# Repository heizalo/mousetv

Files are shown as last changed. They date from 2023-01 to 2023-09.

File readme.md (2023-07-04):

# MouseTV project:
testIR

This is a work in progress will include a changelog as the project keeps on growing. 

In the most recent version of our Python script, we've changed it to continuously record video to address issues we encountered with door opening and closing. Additionally, we have implemented functionality to save recordings in separate folders with timestamps, making organization and access much more convenient.

2022- tqdm added for progressbar

-This project uses an inexpensive Raspberry Pi 4. Using a python script for triggers and the recording in an operant chamber. This could be paired with DLC or SLEAP as a post process

-Magnetic door sensor added

-Script that uses the mag door sensor was implemented

Early 2023:

-New scripts were generated for run and record

-schedule library has been added for scheduled recordings

-Python script has been changed to continuosly recording due to issues when opening the door and closing.

-New design has been completed

-Excel CSV files will be use to cut/snip videos as a post processing

-tqdm has been removed

May 2023 :

-Library "schedule" was added

-New script generated using schedule added

-Magnetic door sensor was removed

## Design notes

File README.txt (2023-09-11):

This project uses an inexpensive raspberry pi 4. 

Here are some part that will be needed in order to make it work:

-Magnetic door sensor
-Raspberry pi camera CSI connector
-3d printed parts

This code built was created keeping in mind that the Universities Internet security constricted us from uploading files from/to network. In order to adapt to the current restriction this script was developed. The main idea here, is to use opening the door as a trigger to either continue to record or skip to the next name on the video.txt file.

First, power savings mode and the headless feature on a raspberry pi MUST be deactivate/activated 
Second, make sure the right GPIO is selected (no PIN)
Third, this script eventually will have a way to write files into a portable USB flash drive for easy storage and removal.
Fourth, make sure video.txt file has been updated with mouse name and time. Example file as how it can be done is shared , "example-video-txt". The name of the mouse/cohort must be included first adding ".h264" and leaving a space " " and after that adding the time in seconds "100 " 

Currently, the main OS has been cloned and stored for easy access in case the current OS gets corrupted. 

--------------------------------------------------------------------------------------------------------------------------------------------------------------------------------------------------------------------------------

MouseTV project:

This project was created to be able to record and keep track of mice running set schedules, males and females. 

Let's start with the set up and things that you might need in order to have the Raspberry Pi set up:
Version of  Raspberry Pi, we are using the(Legacy) OS normally known as Debian 10 (buster) (https://www.raspberrypi.com/software/operating-systems/)
The easiest way to get it burned/flashed is using Raspberry Pi Imager ( https://www.raspberrypi.com/software/ ) Follow instructions 
Upon hours of testing, it was noticed the power saving mode was putting the Pi to sleep. Power saving mode must be deactivated 

  on terminal:
  go to $sudo nano /etc/xdg/lxsession/LXDE-pi/autostart
  add lines
  @xset s noblank
  @xset s off
  @xset dpms
  
  Go to $sudo nano /etc/lightdm/lightdm.conf
  Add below line in to SeatDefault (or Seat:* in newer LightDM versions) section.
  SeatDefaults]
  xserver-command=X -s 0 -dpms
  Restart your Raspberry Pi.
  
  Lastly, network disabling (power saving mode as well)
  Check ,
  sudo iw wlan0 get power_save
  if it is "on" then execute
  sudo iw wlan0 set power_save off

Normally, there is not a need for a monitor to be connected at all times to the raspberry pi and for that it is necesary to have a "headless" pi, without it, it will not boot if not connected to a monitor. 
Adding hdmi_force_hotplug=1 to /boot/config.txt seems to have solves the problem.

Our interface for running the script is using SSH although due to having new people come into our lab we have opted for using VNC viewer which has a nice UI and facilitates easier connections to each raspberry pi

There are few libraries that will need to be updated as time goes by, this part will be updated with time.

-----------------

Some other updates:
- We are currently looking to the addition for ABET to send signal to make our code more robust. (on the works)
- Building a GUI for easy access for undergrads

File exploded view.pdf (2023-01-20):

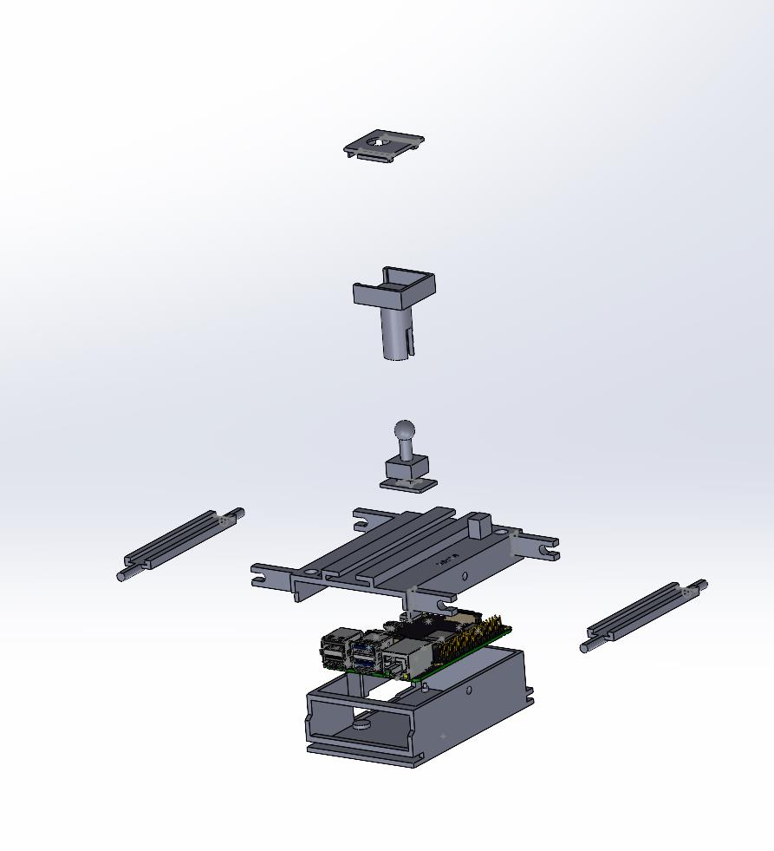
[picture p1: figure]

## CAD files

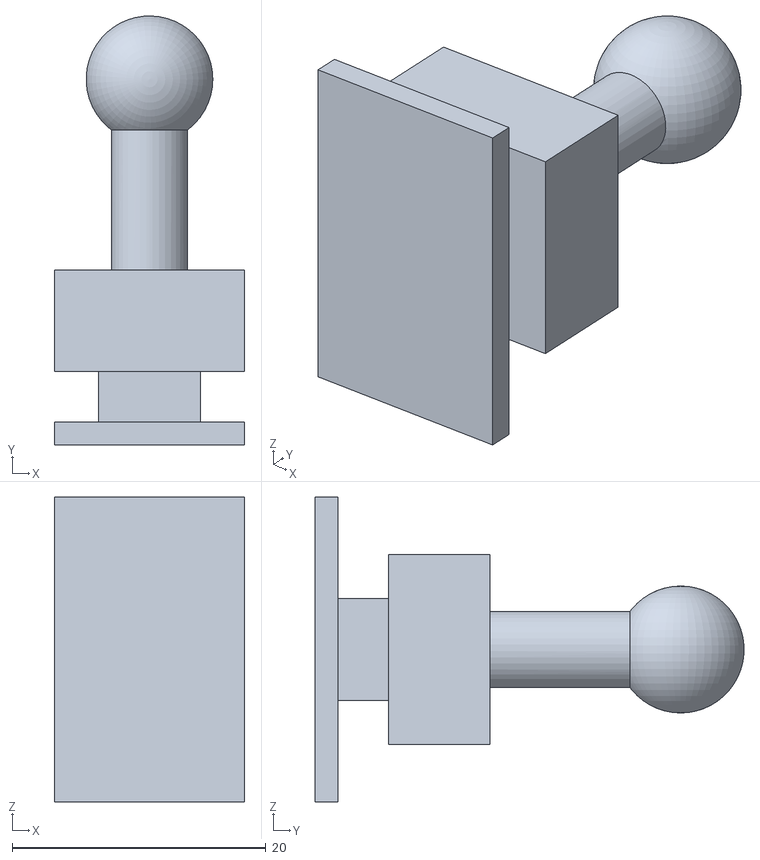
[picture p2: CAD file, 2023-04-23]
stl 2.0/Camera_slider.STL
15.0 x 33.8 x 24.0

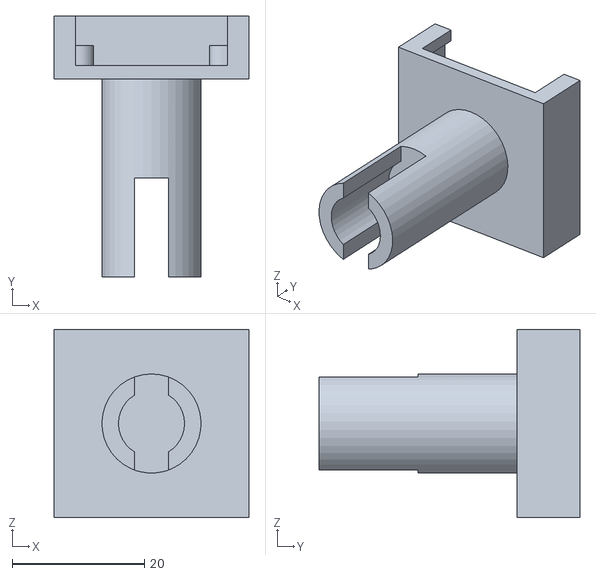
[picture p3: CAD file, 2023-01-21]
stl/CAMERA HOLDER .STL
29.5 x 39.5 x 28.5

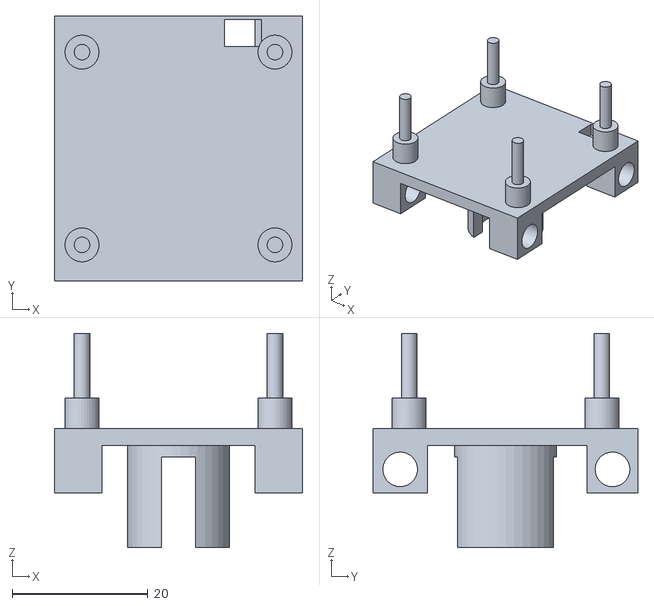
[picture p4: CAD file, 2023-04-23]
stl 2.0/final_bottom_camera.STL
36.5 x 39.0 x 31.5

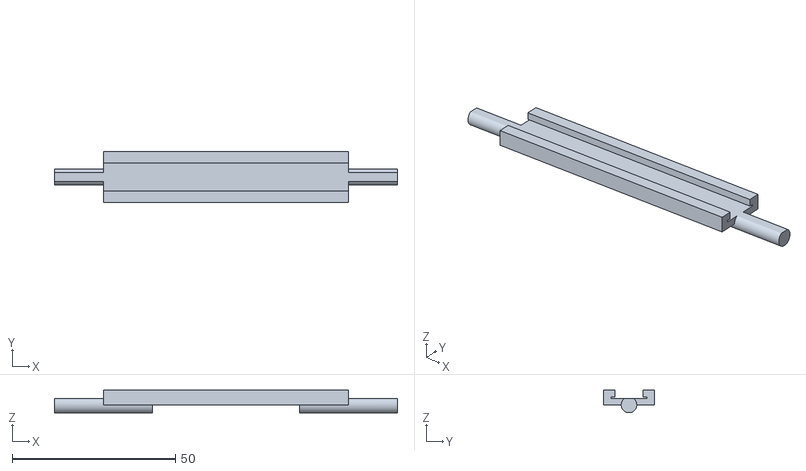
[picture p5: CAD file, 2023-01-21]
stl/LED HOLDER.STL
105.0 x 15.5 x 6.90

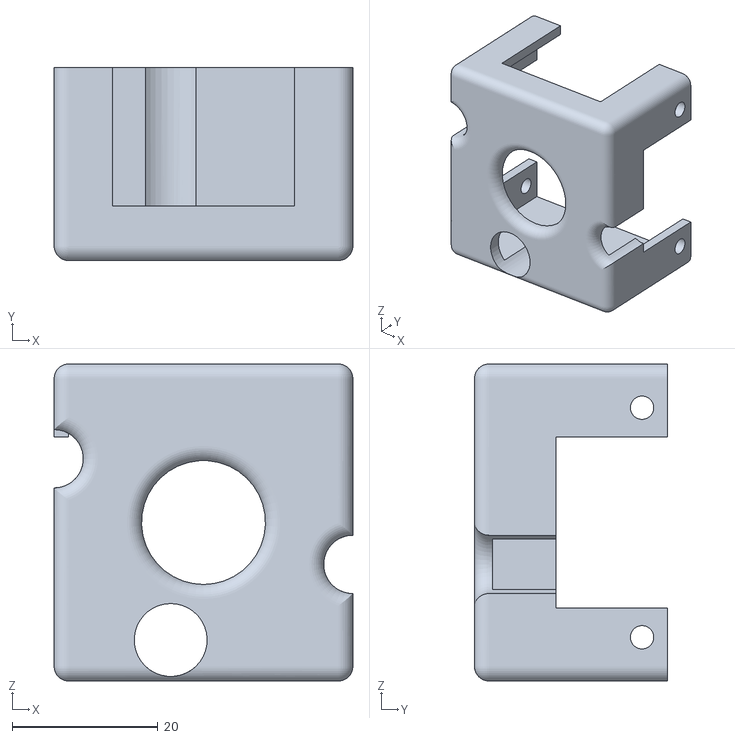
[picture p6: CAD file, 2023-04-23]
stl 2.0/final_top cover.STL
41.0 x 26.5 x 43.5

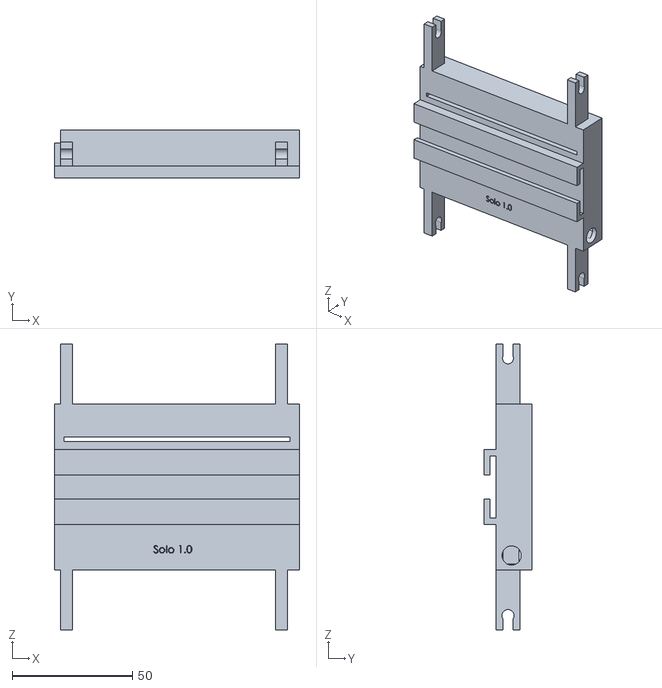
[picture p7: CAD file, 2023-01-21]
stl/TOP LID .STL
102.0 x 20.0 x 119.0

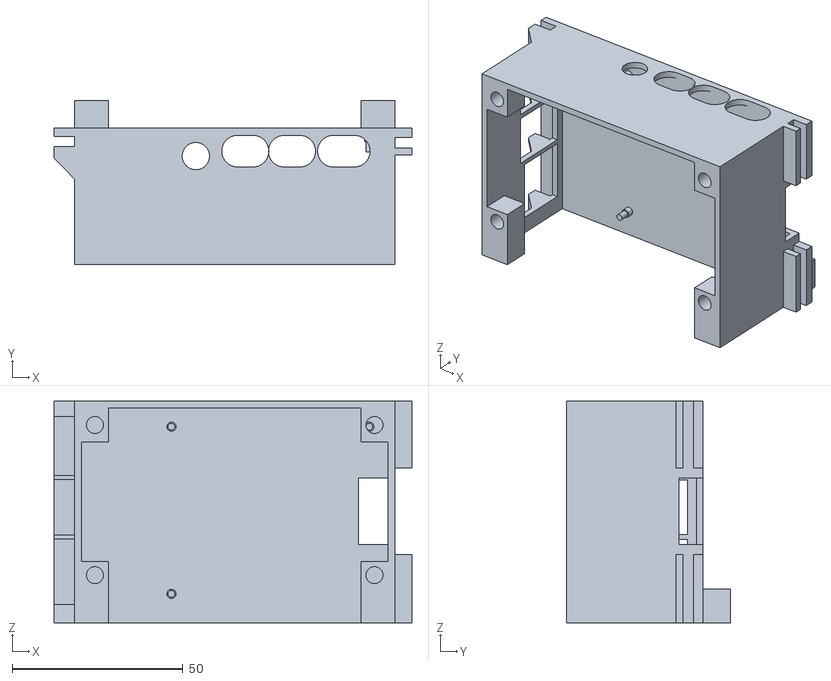
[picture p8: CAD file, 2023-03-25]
stl 2.0/new casing for fan1.STL
104.9 x 48.0 x 65.0

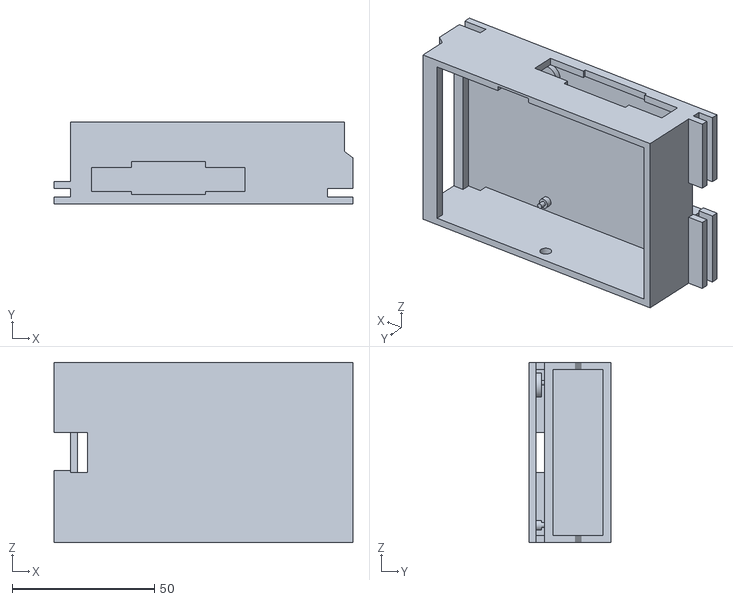
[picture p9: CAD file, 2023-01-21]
stl/raspberry pi case.STL
105.2 x 29.0 x 63.5

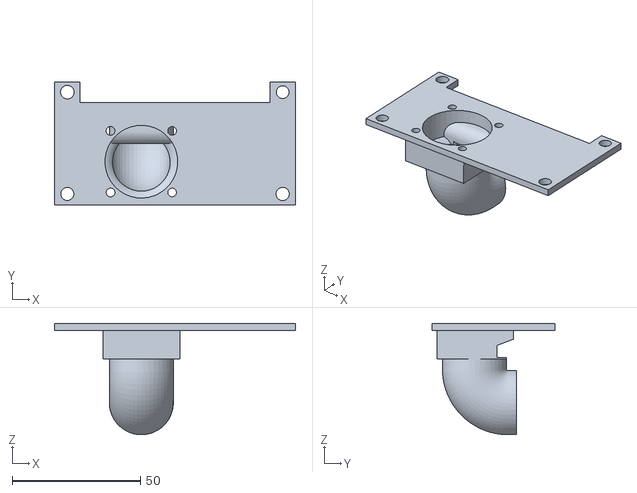
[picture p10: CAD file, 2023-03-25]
stl 2.0/fandoor.STL
93.9 x 48.0 x 43.4

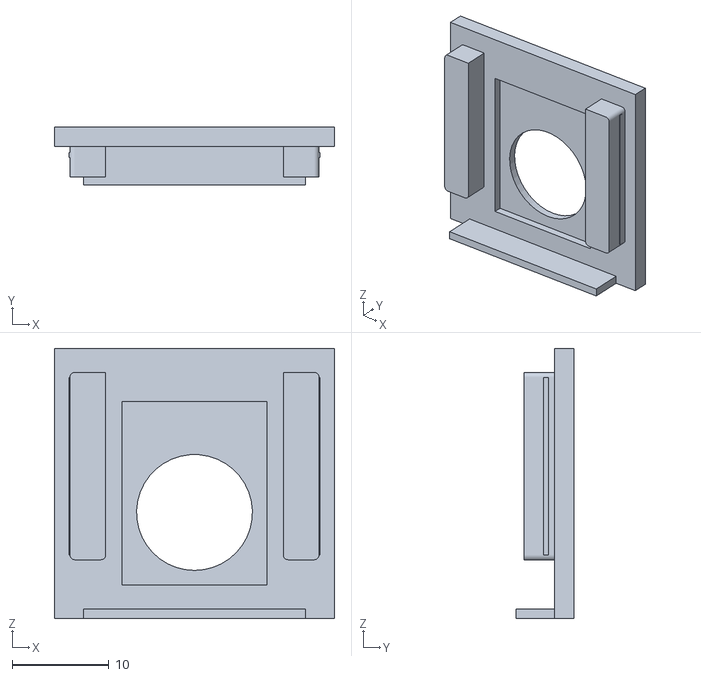
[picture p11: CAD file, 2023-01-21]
stl/mask raspberry camera.STL
29.0 x 6.00 x 28.0

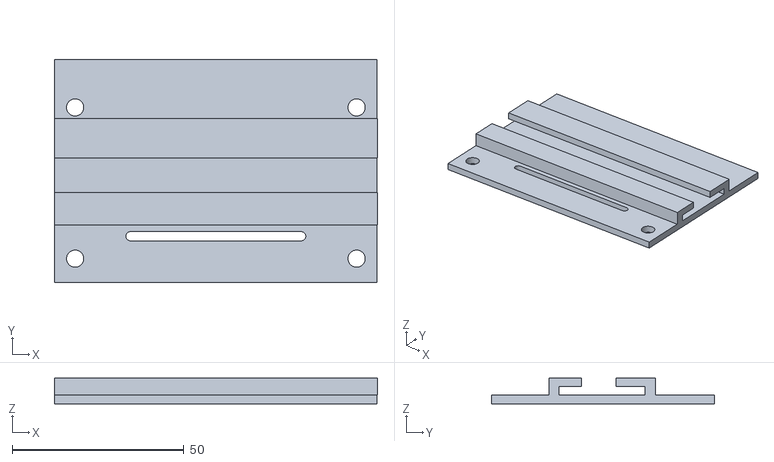
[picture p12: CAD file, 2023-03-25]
stl 2.0/railtop.STL
94.0 x 65.0 x 7.54

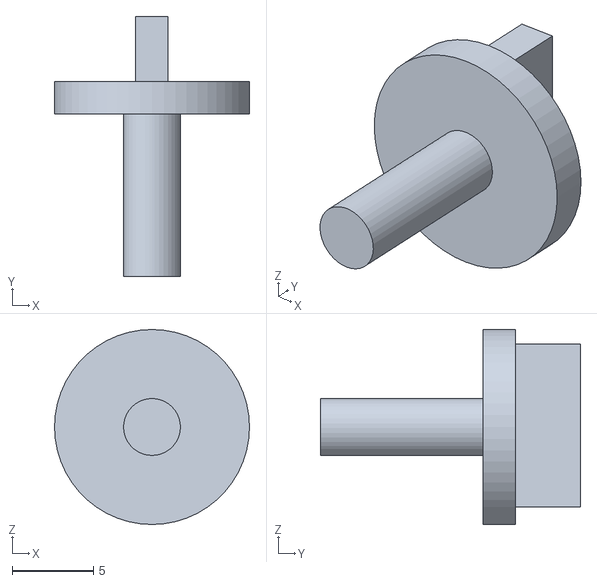
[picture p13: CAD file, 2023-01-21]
stl/pluguppercover.STL
12.0 x 16.0 x 12.0

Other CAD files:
stl/camholderslider.STL

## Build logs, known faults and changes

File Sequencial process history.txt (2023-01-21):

Process on Raspberry Pi

Code written for raspberry pi, only local data at the moment. DONE
Possible router addition ( router purchased waiting for trials)

3d printed stuff for raspberry pi. POSSIBLY NEW BUILDS/PRINTS

	Coming out with new prints, designs for easy attachment to the aluminum top part
	Will be designing all in one enclosure for the raspberry pi, needs long jumper cord from raspberry pi to camera
	Possible final design for the casing
	Looking for possibilities of battery powered

LED strip coded. 

Putting camera code and light code together. 

Looking for a way to connect it to the network. 
raspberry pi only connects to the “guest network” at the moment, need to be coded to work with universities “euroam” since it won't be able to connect to other software for remote manipulation (SSH and VNC)

At the moment, raspberry pi can not connect to WIFI
CHEAP WIFI ROUTER BOUGHT, can be remotely accessed 
Way around the network usage is local storage with flashdrive
Will try to re-route to be saved on flashdrives at the moment.

Sending data over network for storage and streaming.
DeepLabCut installation on workstations and home. DONE, need to be tested
DLC installed, waiting to test videos

OS corrupted, trying to reflash Operating system 10/06/2021
OS fully installed, data was moved over.

Final case and lights were installed
Had issues with wiring, shorts and LED being burned out
Code completed to save information on
 usb flash drive “/media/pi/5589-2846/” (https://pimylifeup.com/raspberry-pi-mount-usb-drive/)

Currently trying to fix preview issue from raspberry pi--FIXED ( VNC direct capture)
Fixed issue “headless” raspberry pi ( no monitor needed)

Adding hdmi_force_hotplug=1 to /boot/config.txt seems to have solved the problem. The Pi4 is running headless, and will be accessed via VNC.
Raspberry Pi, seems to get warm, will keep an eye on temperatures
Clone SD just in case.
New addition to the code, for automatic mp4 conversion normally videos are being saved as “.h264”
Code has been saved on raspberry pi  https://www.theamplituhedron.com/articles/How-to-convert-h264-to-mp4-with-MP4Box-on-Raspberry-Pi-in-Python/
Debugging at the moment

 Static IP
https://www.weigu.lu/sb-computer/raspi_tips_tricks/index.html

New code, replacing old code. 

Moving on with IR instead of red LED lights. 

Script uses magnetic door sensor for trigger

Avoiding issue in regard sending data into the raspberry pi over the network. Connecting over ssh to make and re-write or write any other additions to exiting text file. The university limits the data input and output from raspberry pi. 

Successfully able to add order to record videos

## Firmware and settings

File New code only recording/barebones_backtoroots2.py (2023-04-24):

from picamera import PiCamera
import time
import schedule

def start_recording(while_recording):
    if while_recording == false:
        return
    
    print("Starting to record...")
    storage_location = "/mnt/usb1/"
    
    # filename includes time and date
    timestamp = time.strftime("%Y-%m-%d_%H-%M-%S", time.localtime())
    filename = f"{timestamp}.h264"

    # Initialize PiCamera object
    camera = PiCamera()

    # Set camera resolution and framerate the res
    camera.resolution = (640, 480)
    #camera.framerate = 20

    # Start recording
    camera.start_recording(filename)

    # Record for in secods 60 sec = 1 min
    camera.wait_recording(60)

    # Stop recording and release camera, camera.close has to be set so it can record once again
    camera.stop_recording()
    camera.close()

    print("Recording has stopped.")

# Schedule "day" can be replaced with monday, tues... these can be removed if only 1 day per week needs to be active
schedule.every().monday.at("19:12").do(start_recording)
schedule.every().tuesday.at("19:12").do(start_recording)
schedule.every().wednesday.at("19:12").do(start_recording)
schedule.every().thursday.at("19:12").do(start_recording)
schedule.every().friday.at("19:12").do(start_recording)


start_recording()

# while loop running scheduled script
while True:
    schedule.run_pending()
    time.sleep(1)

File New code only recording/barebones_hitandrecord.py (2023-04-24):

from picamera import PiCamera
import time
import datetime
import schedule

#recording can be set in min auto convertion below 
time_to_record = int(input("How long will you need to record?  "))
cohort_name = input("What is the cohort name?  ")

print("Starting to record...")

#location if folders have been created add after /mnt/usb1/xxx
storage_location = "/mnt/usb1/"

    

filename = storage_location + cohort_name + datetime.datetime.now().strftime("%Y%m%d__%H-%M-%S ") + ".h264"

# camera settings
camera = PiCamera()


camera.resolution = (640, 480)
#camera.framerate = 20

# Start recording
camera.start_recording(filename)

#just a conversion, min to seconds   
time_conversion = (time_to_record * 60)

camera.wait_recording(time_conversion)

# Stop recording and release resources
camera.stop_recording()
camera.close()

print("Recording stopped.")
